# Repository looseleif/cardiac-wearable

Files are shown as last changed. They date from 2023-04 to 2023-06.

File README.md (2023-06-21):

<h1> aWear Monitor: A Passive and Affordable <br>
Atrial Fibrillation Detection Device
</h1>

| _Team member_ 	| _Role_ 	| _Contact_ 	|
|---	|---	|---	|
| Chase Anderson 	| Hardware 	| and08479@umn.edu 	|
| Yuriy Shevchenko 	| Hardware 	| shevc011@umn.edu 	|
| Seth Gunderson 	| Detection algorithm 	| gunde520@umn.edu 	|
| Vaibhav Shirole  	| Firmware 	| shiro019@umn.edu 	|
| Matthew Kukla 	| Firmware 	| kukla013@umn.edu 	|

### What is aWear
Atrial fibrillation is an irregular heartbeat or arrhythmia that can lead to stroke, heart failure, and other heart complications. [7] A severe lack of affordable and easy-to-use, passive, and noninvasive monitoring devices for atrial fibrillation prompted the development of aWear. aWear is a device designed to detect atrial fibrillation in patients passively and wirelessly. The device is designed to be inconspicuous and noninvasive and worn under a regular watch. It monitors the user’s heart activities and if atrial fibrillation is suspected, warns the user. This device uses photoplethysmography to monitor the heart. Detection of atrial fibrillation is done by calculating the coefficient of variation and the turning point ratio after the signal is filtered. The results were a wearable device that lasts approximately 72 hours on a charge and detects atrial fibrillation with an accuracy of 90.48% while remaining under $50 in production cost.
<p align="middle">
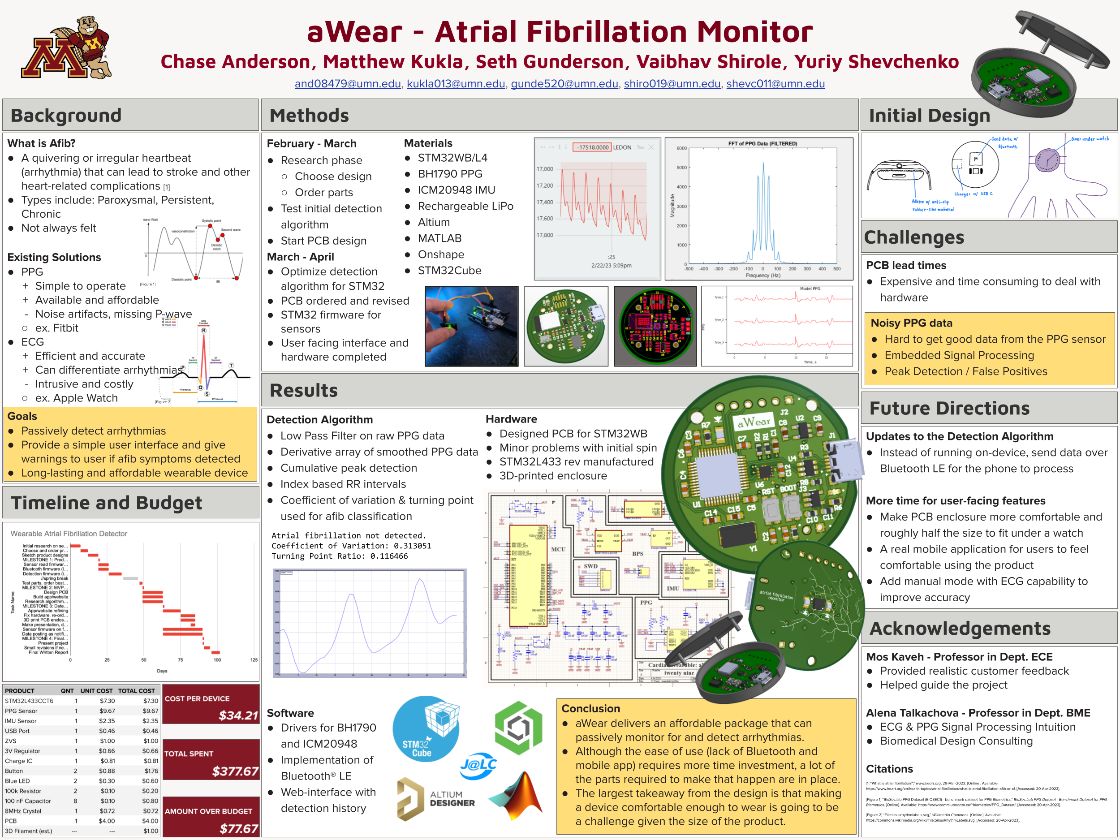
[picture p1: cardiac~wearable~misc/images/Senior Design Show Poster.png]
“design-show-poster”
  
</p>
<p align="middle">
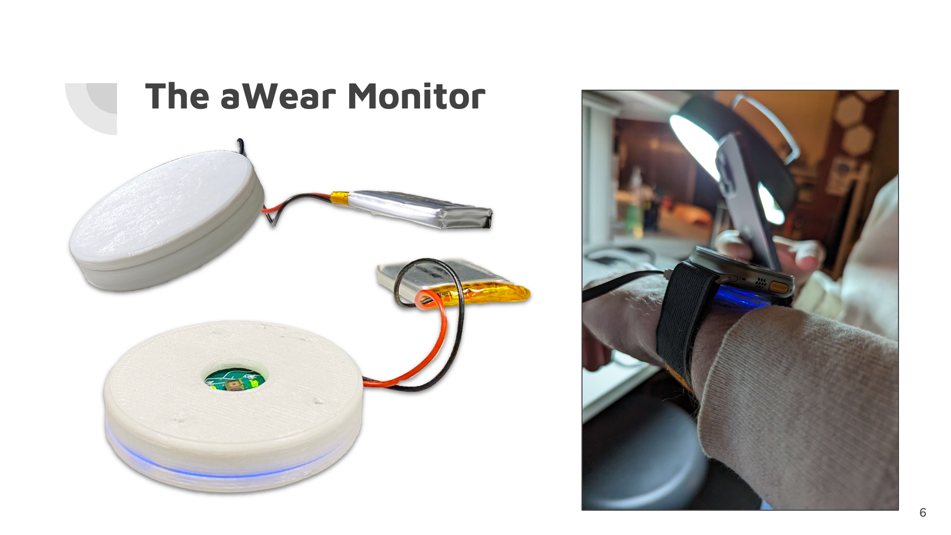
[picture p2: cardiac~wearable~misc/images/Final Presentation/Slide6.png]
“hardware-interface”
  
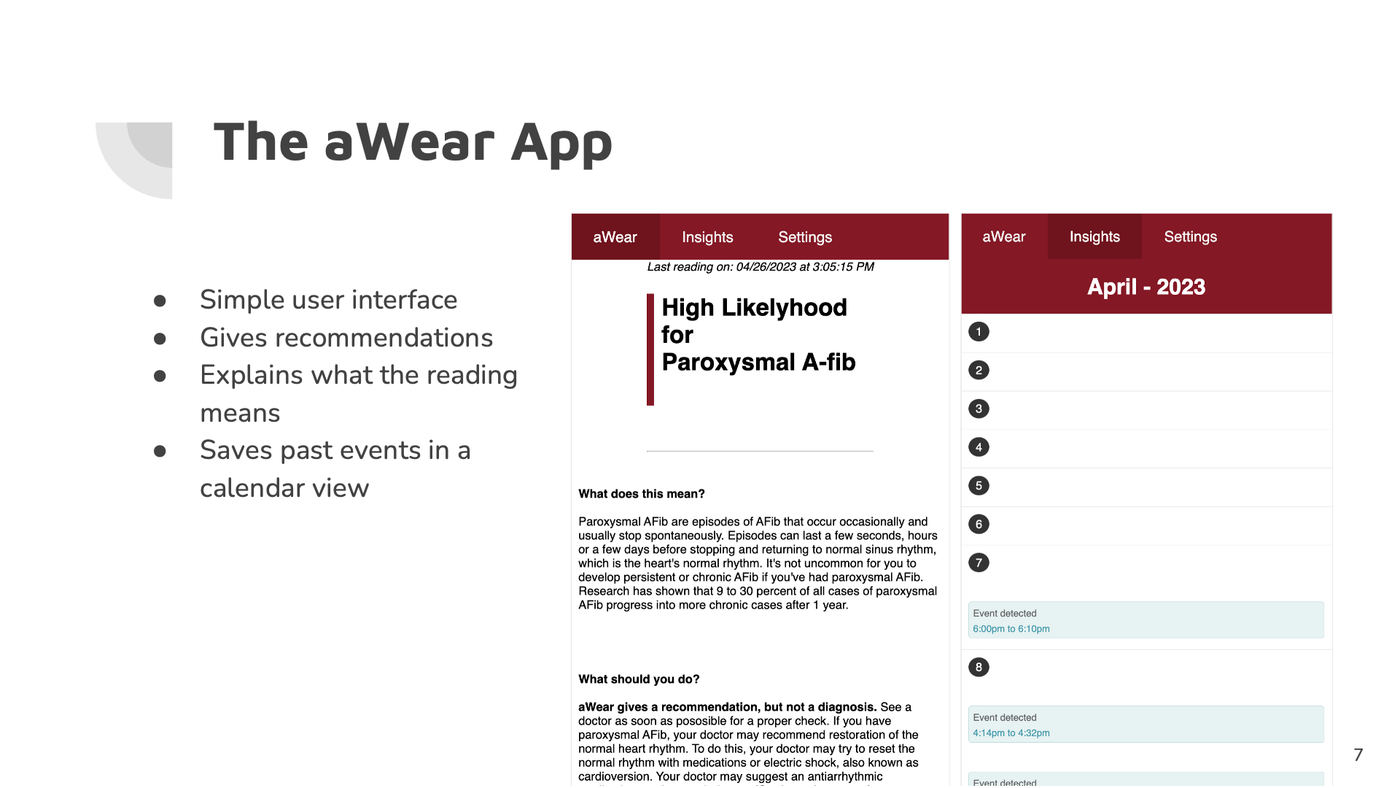
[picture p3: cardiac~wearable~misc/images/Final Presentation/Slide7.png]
“app-interface”
  
</p>

### Compared to the Competition
<p align="middle">
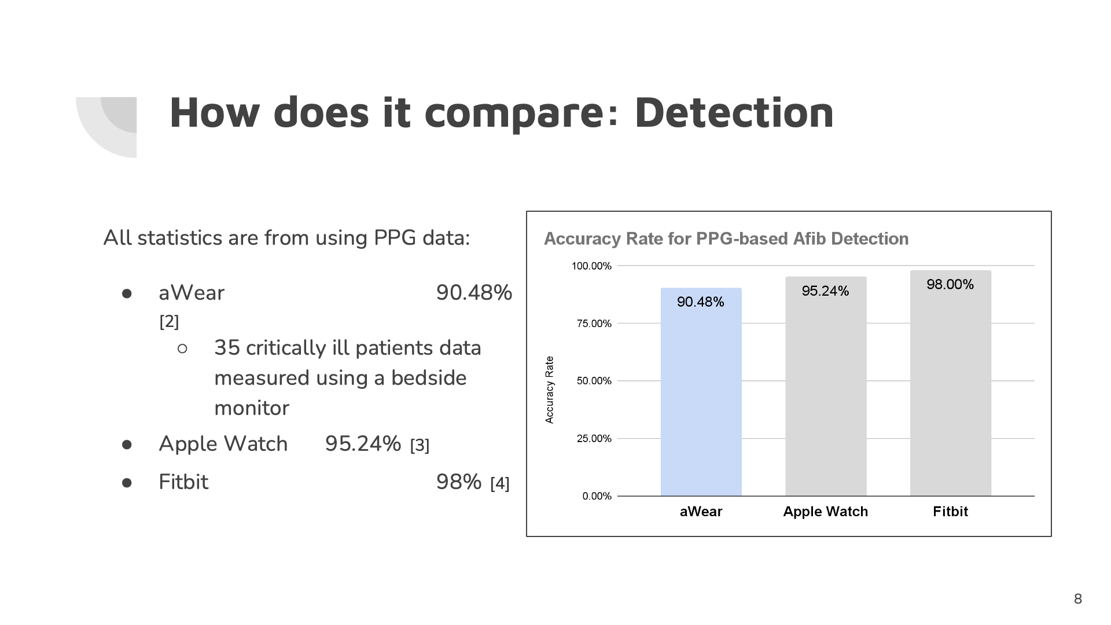
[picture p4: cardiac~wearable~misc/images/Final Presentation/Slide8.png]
“performance”
  
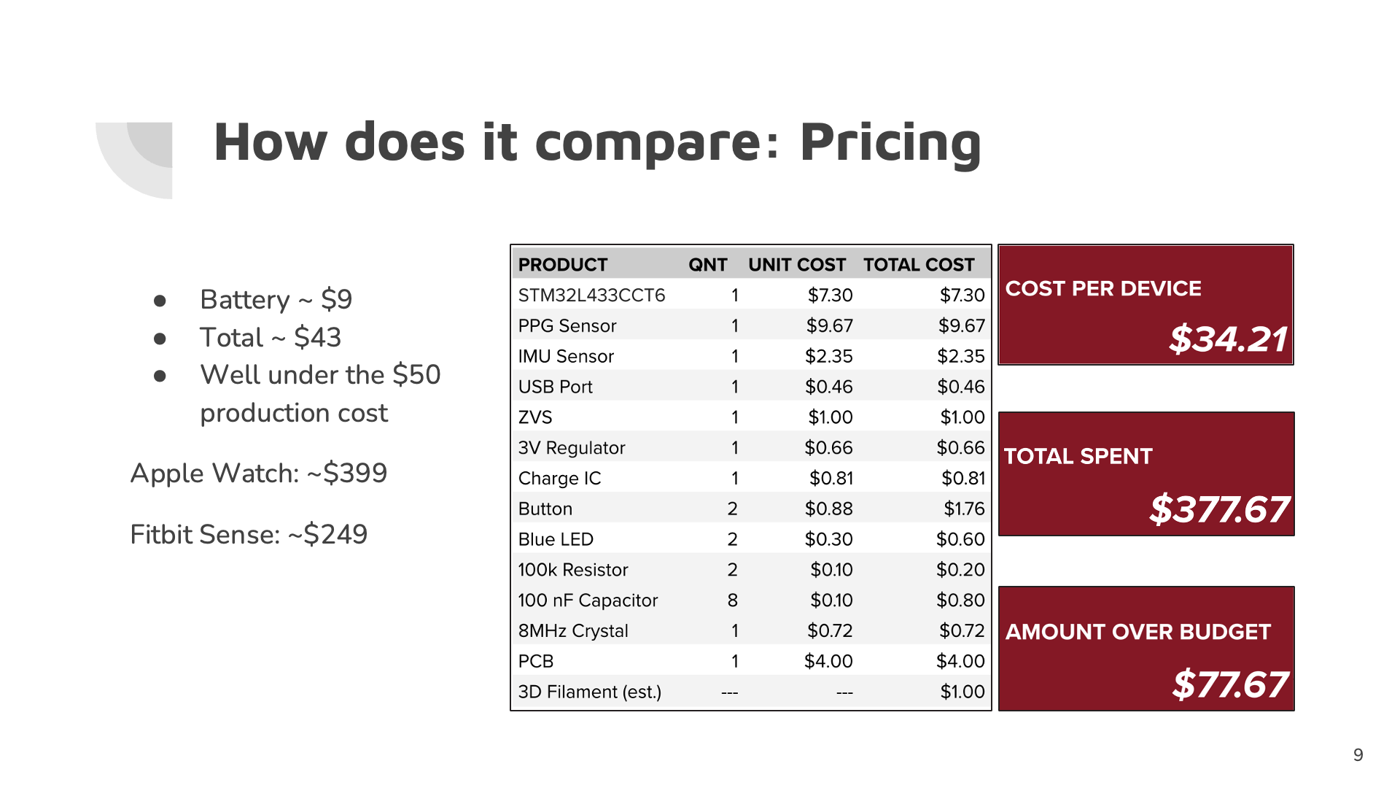
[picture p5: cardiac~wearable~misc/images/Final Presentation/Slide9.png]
“cost-of-production”
  
</p>

## Development

<details>
  <summary>Hardware</summary>
  <p align="middle">
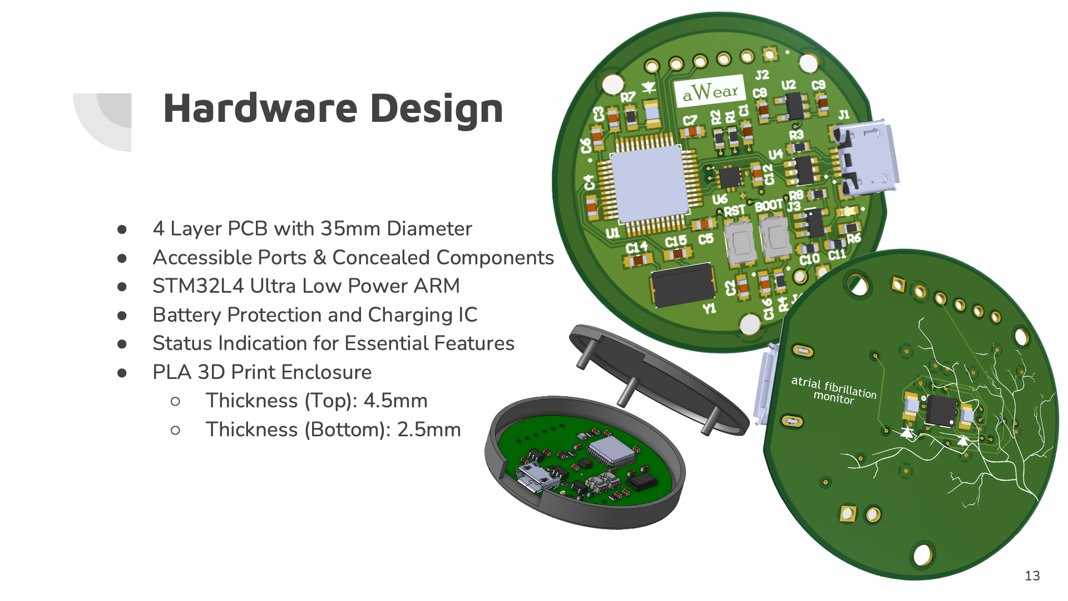
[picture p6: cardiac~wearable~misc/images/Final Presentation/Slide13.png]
“hardware-design”
    
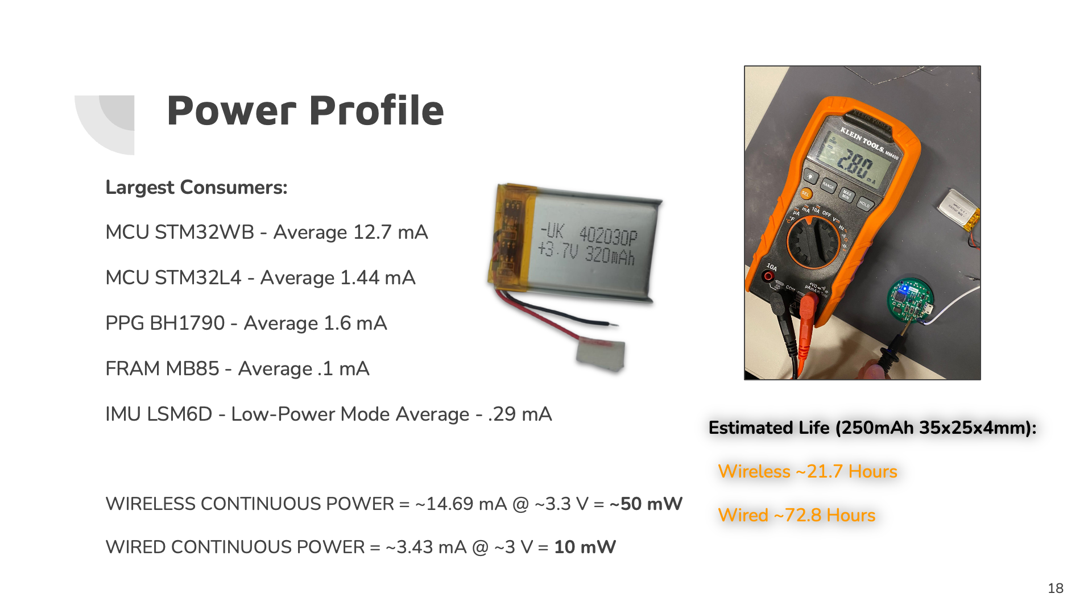
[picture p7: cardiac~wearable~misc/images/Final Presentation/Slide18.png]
“battery-profile”
    
  </p>
</details>

<details>
  <summary>Software</summary>
  <p align="middle">
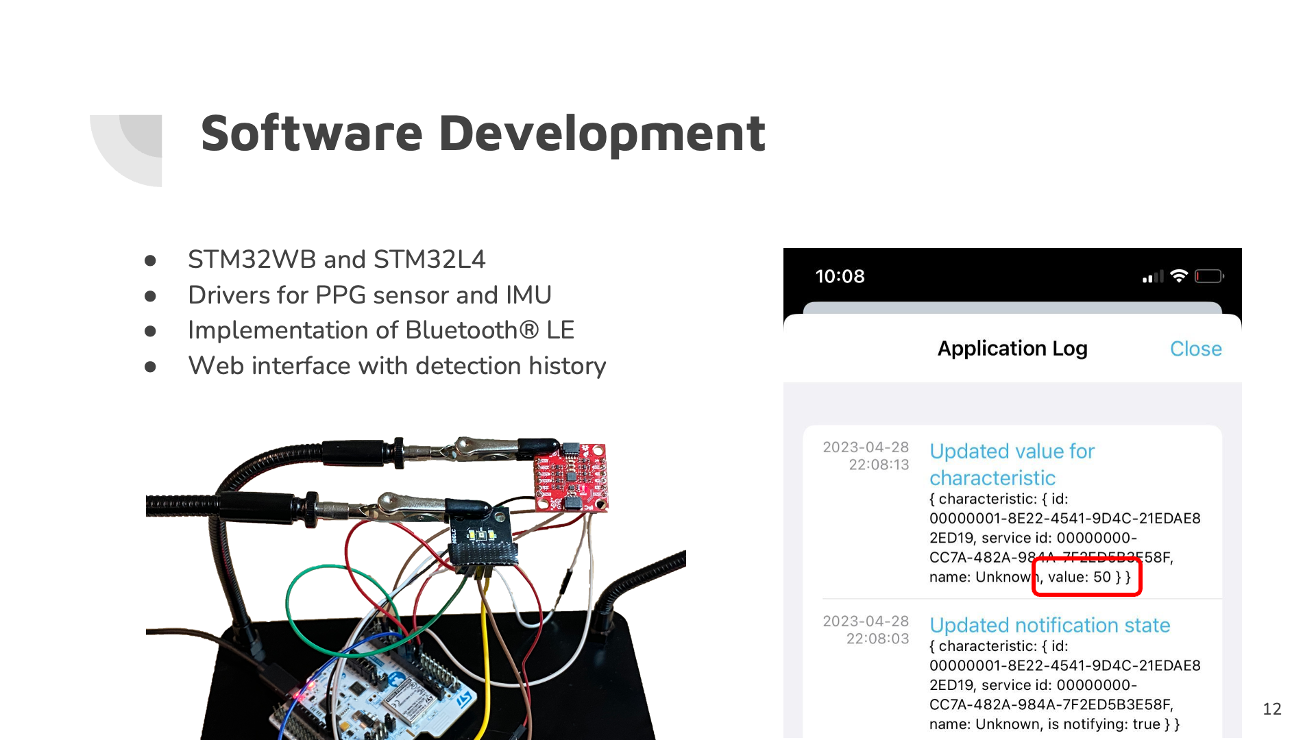
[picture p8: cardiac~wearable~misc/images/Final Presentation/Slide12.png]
    
  </p>
</details>

<details>
  <summary>Detection Algorithm</summary>
  <p align="middle">
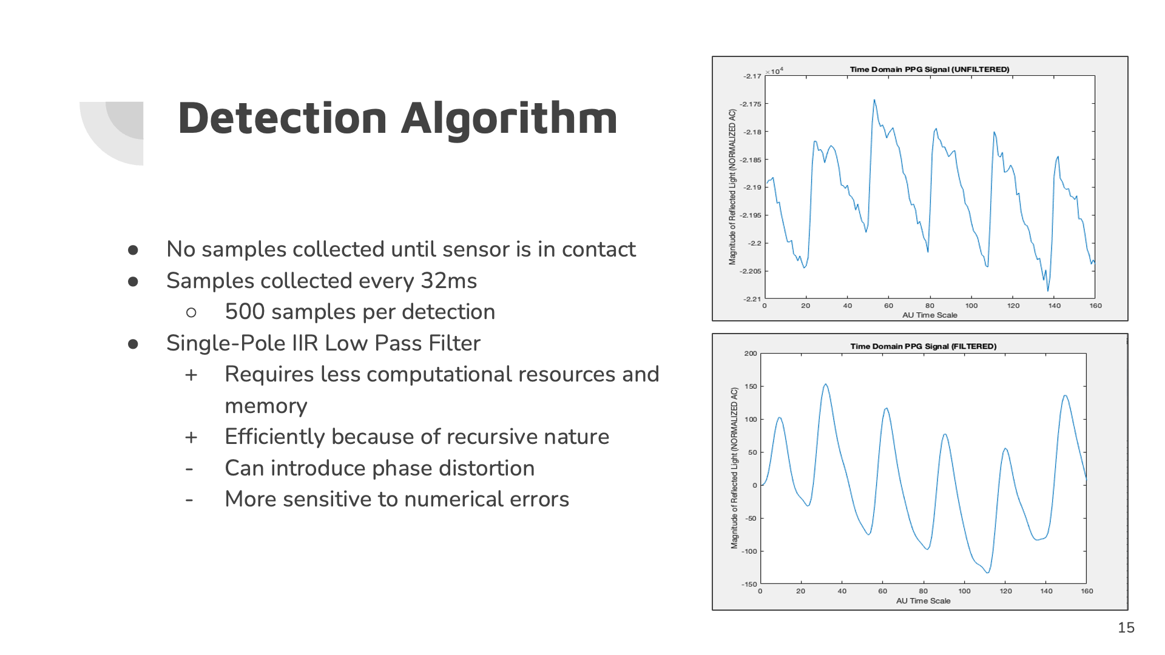
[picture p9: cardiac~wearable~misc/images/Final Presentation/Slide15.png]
“detection-algorithm-1”
    
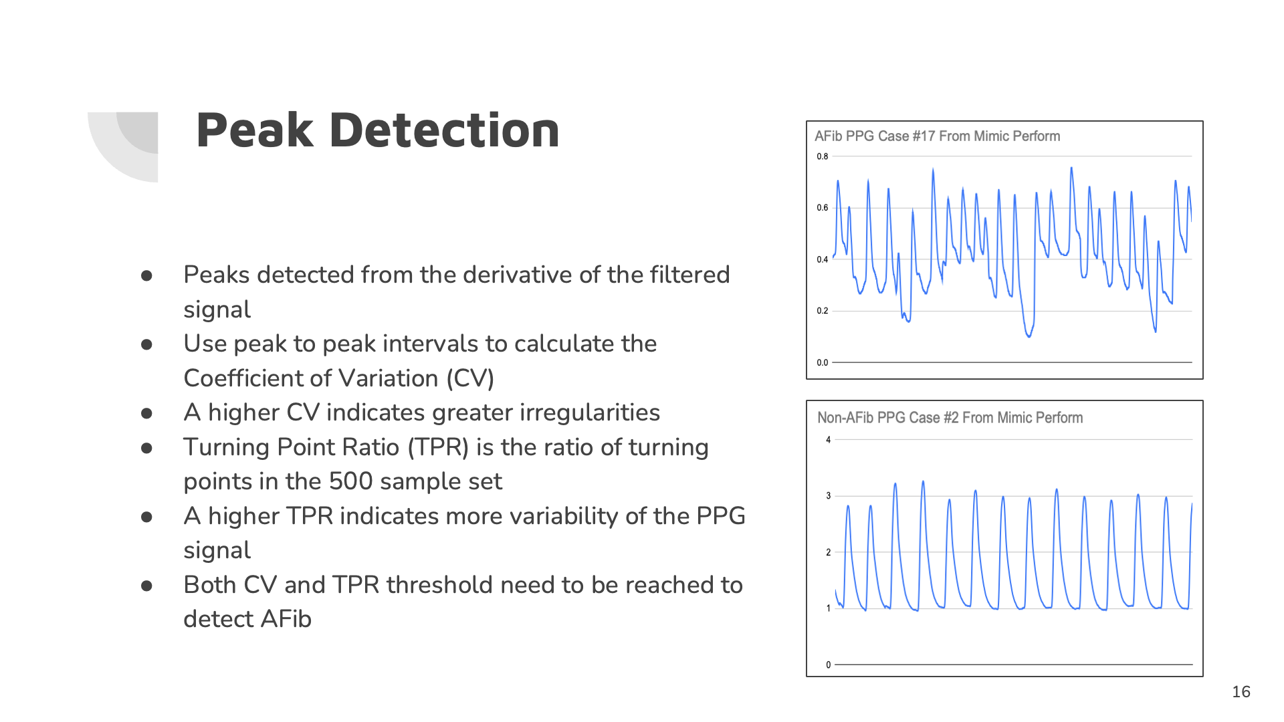
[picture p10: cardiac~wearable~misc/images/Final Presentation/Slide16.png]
“detection-algorithm-2”
    
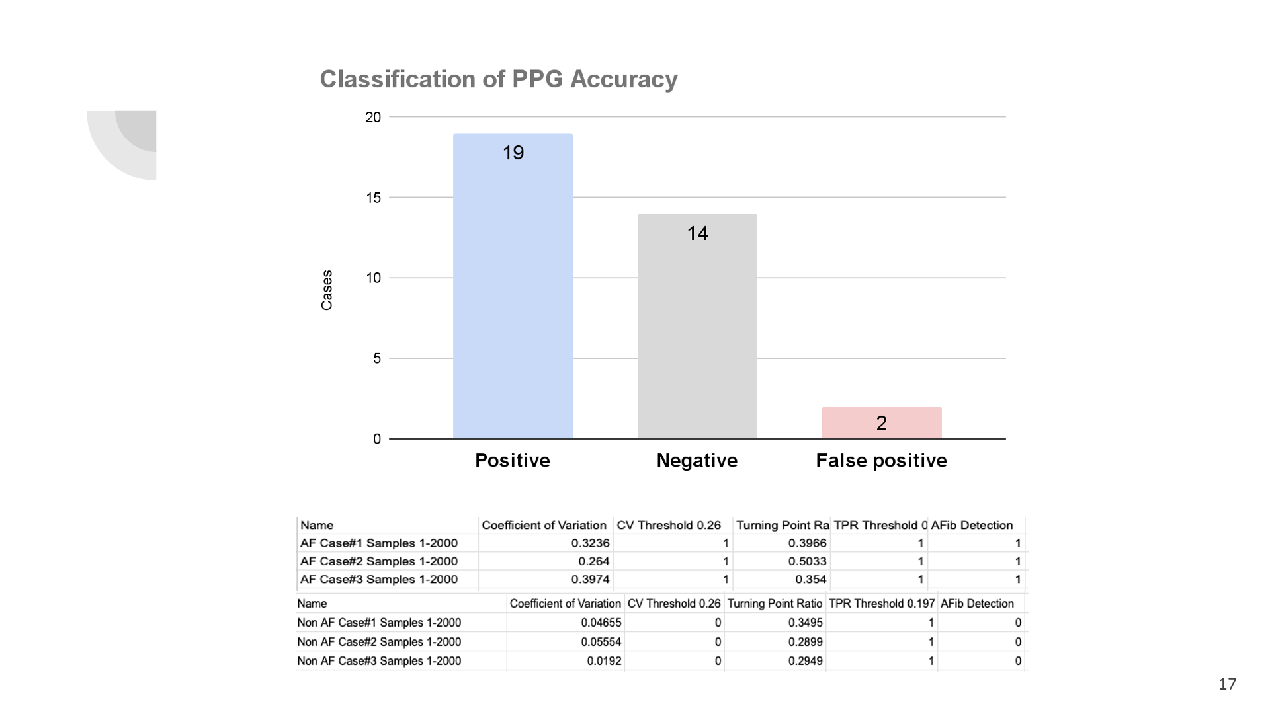
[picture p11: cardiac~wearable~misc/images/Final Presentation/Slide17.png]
“detection-algorithm-3”
    
  </p>
</details>

<details>
  <summary>Project Timeline</summary>
  <p align="middle">
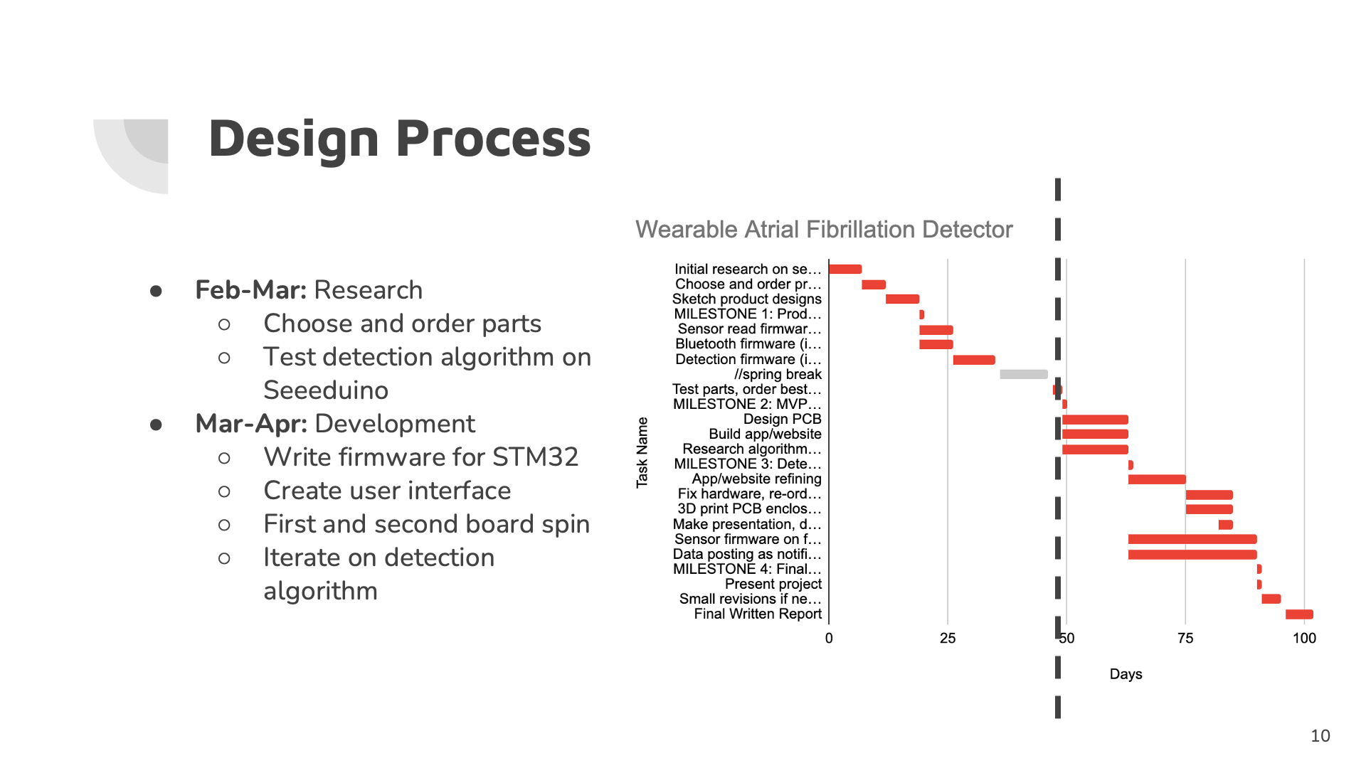
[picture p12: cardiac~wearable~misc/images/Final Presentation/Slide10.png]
    
  </p>
</details>

<br>
<br>
<br>
<br>
<br>
<br>
<br>
<br>
<br>
<br>
<br>
<br>
<br>
<br>
<br>
<br>
<br>
<br>
<br>
<br>

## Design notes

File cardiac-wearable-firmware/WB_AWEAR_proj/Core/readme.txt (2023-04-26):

The USART is configured as follows:
    - BaudRate = 115200 baud
    - Word Length = 8 Bits (7 data bit + 1 parity bit)
    - One Stop Bit
    - Odd parity
    - Hardware flow control disabled (RTS and CTS signals)
    - Reception and transmission are enabled in the time
    
Bluetooth?
custom_app.c line 85

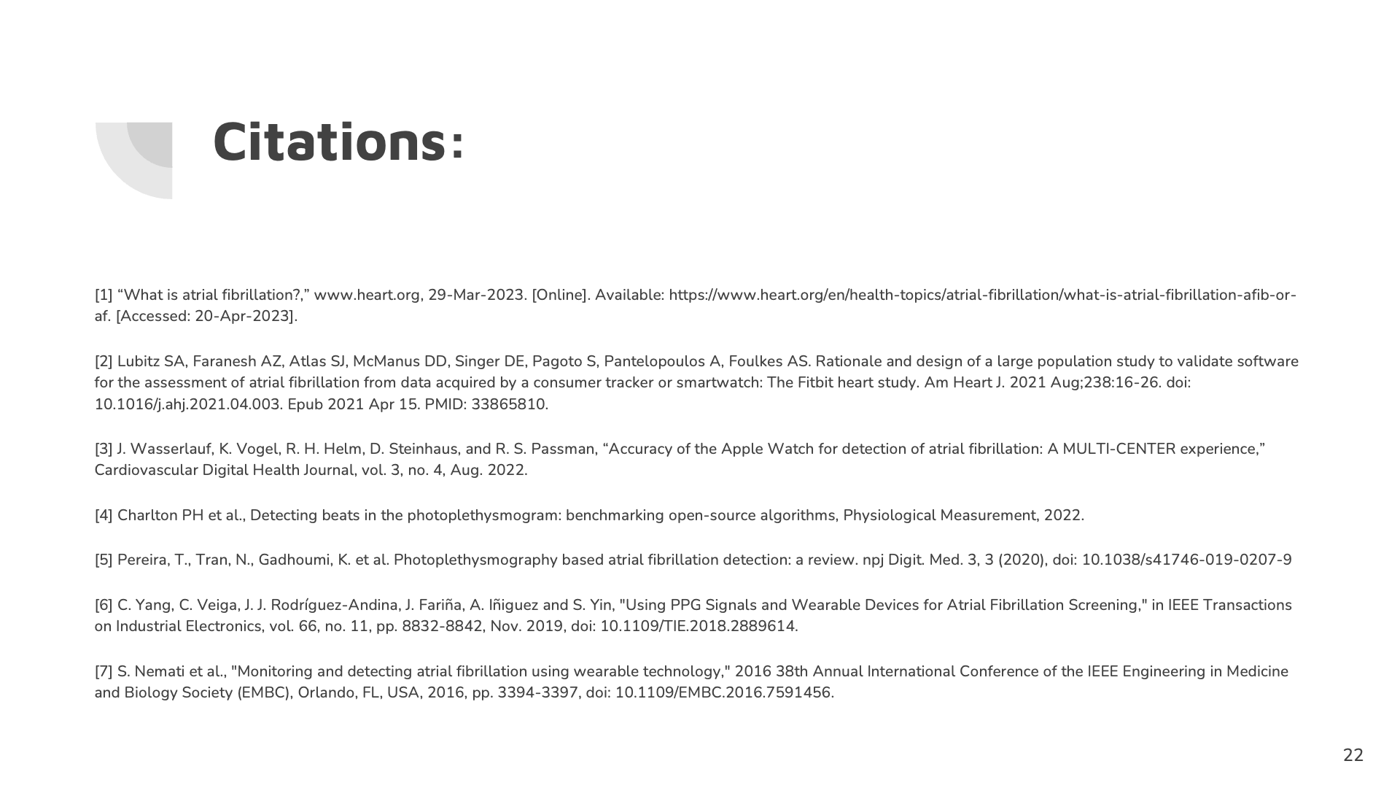
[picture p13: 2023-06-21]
cardiac~wearable~misc/images/Final Presentation/Slide22.png

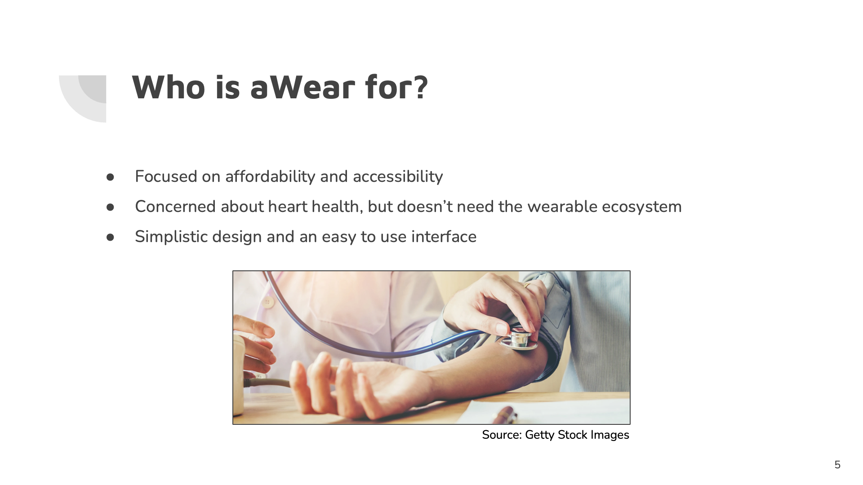
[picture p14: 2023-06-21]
cardiac~wearable~misc/images/Final Presentation/Slide5.png

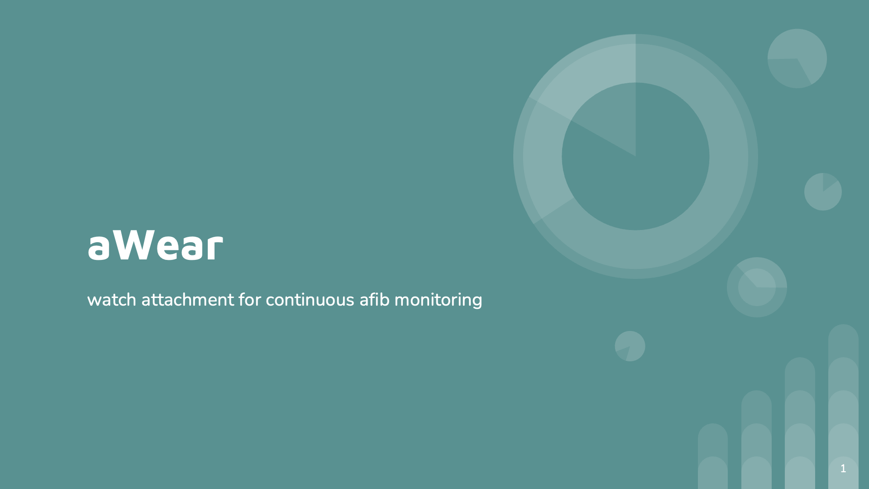
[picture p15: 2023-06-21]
cardiac~wearable~misc/images/Final Presentation/Slide1.png

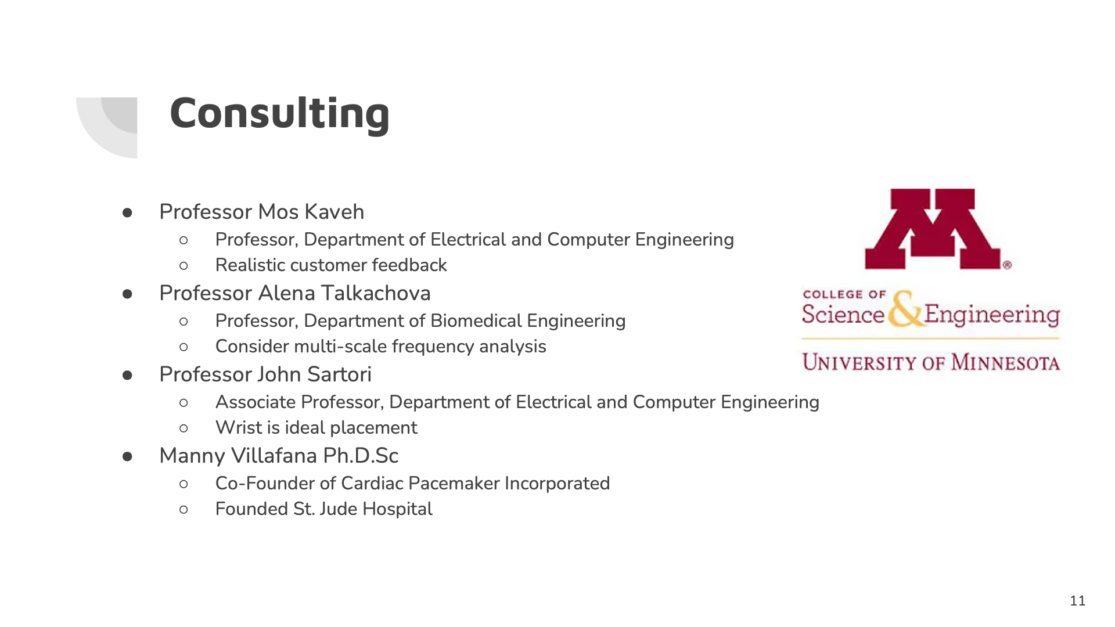
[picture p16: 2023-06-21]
cardiac~wearable~misc/images/Final Presentation/Slide11.png

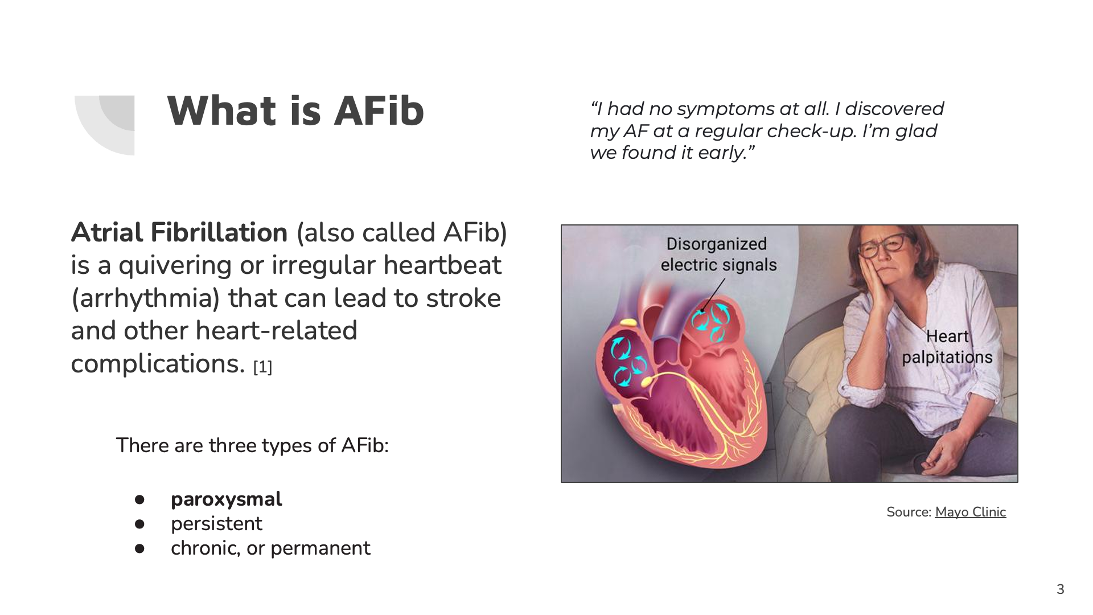
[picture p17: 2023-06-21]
cardiac~wearable~misc/images/Final Presentation/Slide3.png

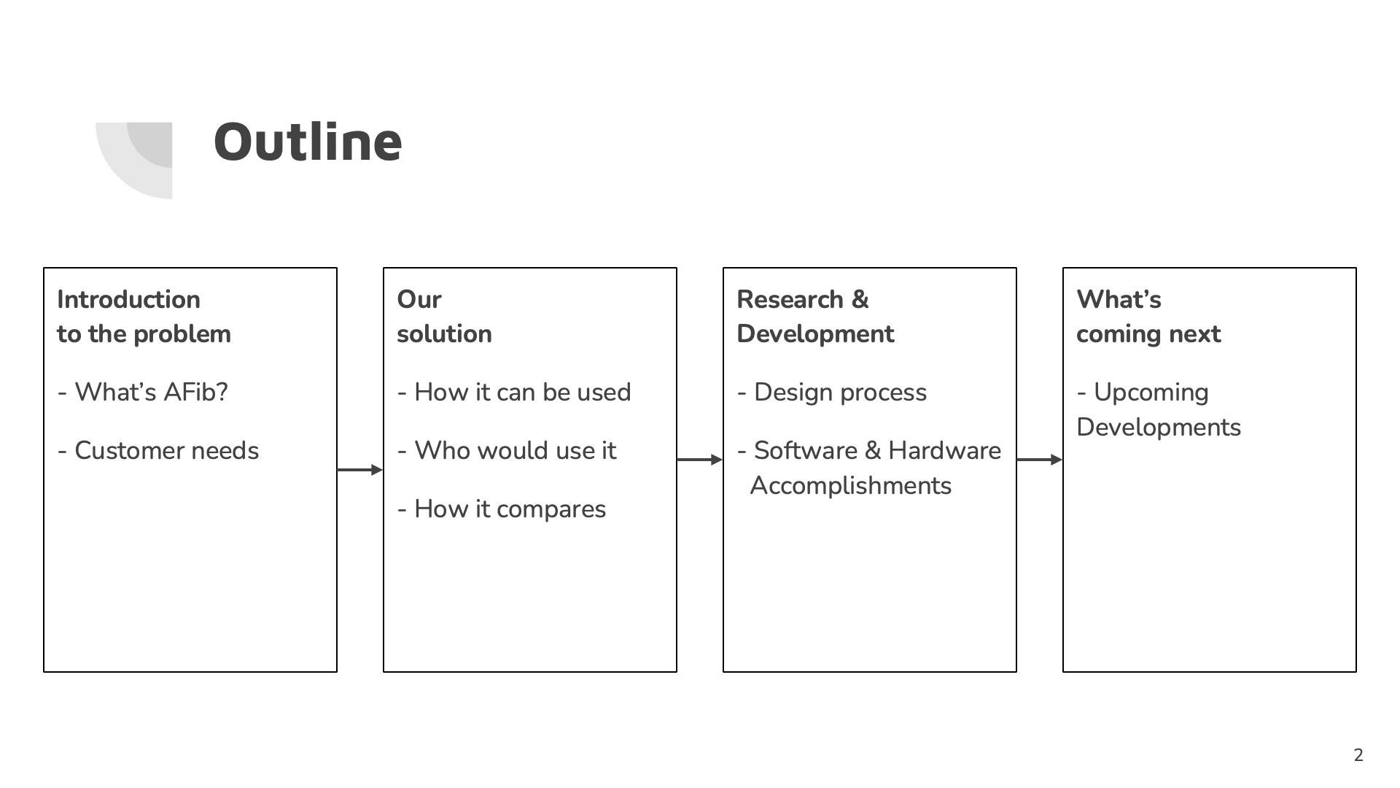
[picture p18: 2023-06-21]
cardiac~wearable~misc/images/Final Presentation/Slide2.png

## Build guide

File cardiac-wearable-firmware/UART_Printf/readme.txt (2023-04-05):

/**
  @page UART_Printf UART Printf example
  
  @verbatim
  ******************** (C) COPYRIGHT 2017 STMicroelectronics *******************
  * @file    UART/UART_Printf/readme.txt 
  * @author  MCD Application Team
  * @brief   Description of the UART Printf example.
  ******************************************************************************
  * @attention
  *
  * Copyright (c) 2017 STMicroelectronics.
  * All rights reserved.
  *
  * This software is licensed under terms that can be found in the LICENSE file
  * in the root directory of this software component.
  * If no LICENSE file comes with this software, it is provided AS-IS.
  *
  ******************************************************************************
   @endverbatim

@par Example Description    

This example shows how to re-route the C library printf function to the UART.
The UART outputs a message on the HyperTerminal.            

The STM32 Nucleo boards integrate the ST-LINK/V2.1 interfacing with the PC and 
offering the following capabilities:
  – Debug and programming port
  – Virtual com port interface
  – Mass storage interface
  – USB power management request for more than 100 mA power

Once connected to your PC via the ST-LINK port, the STM32 Nucleo board is enumerated 
as a serial communication port USART2 and listed under Ports (COM & LPT) of Windows
Device Manager.

This implementation shows how to retarget the C library printf function to the UART
in order to output the printf message on the Hyperterminal using USART2 interface 
connected to ST-LINK MCU in order to support Virtual Com Port.

The communication port USART2 is configured as follows:
    - BaudRate = 9600 baud  
    - Word Length = 8 Bits
    - One Stop Bit
    - ODD parity
    - Hardware flow control disabled (RTS and CTS signals)
    - Receive and transmit enabled

To identify the Nucleo board VCP, you have just to perform the follwing actions on
your Windows PC: 
    - Click Start, and enter Device Manager into the Search field. Click Device Manager .
    - Double-click Ports (COM & LPT).
    - Find the Nucleo board VCP: STMicroelectronics STLink Virtual COM Port (COM..)

To receive the printf output message on the Hyperterminal, apply this configuration
on your serial terminal:       
    - Port name = COM.. (already identified on Device Manager)
    - Word Length = 7 Bits
    - One Stop Bit
    - Odd parity
    - BaudRate = 9600 baud
    - flow control: None 

@note Care must be taken when using HAL_Delay(), this function provides accurate delay (in milliseconds)
      based on variable incremented in SysTick ISR. This implies that if HAL_Delay() is called from
      a peripheral ISR process, then the SysTick interrupt must have higher priority (numerically lower)
      than the peripheral interrupt. Otherwise the caller ISR process will be blocked.
      To change the SysTick interrupt priority you have to use HAL_NVIC_SetPriority() function.
      
@note The application needs to ensure that the SysTick time base is always set to 1 millisecond
      to have correct HAL operation.

@note The clock setting is configured to have the max product performance (max clock frequency) 
      so not optimized in term of power consumption.

@par Keywords

Connectivity, UART, Printf, Baud rate, RS-232, HyperTerminal, full-duplex

@par Directory contents 

  - UART/UART_Printf/Inc/stm32f4xx_hal_conf.h    HAL configuration file
  - UART/UART_Printf/Inc/stm32f4xx_it.h          Interrupt handlers header file
  - UART/UART_Printf/Inc/main.h                  Main program header file  
  - UART/UART_Printf/Src/stm32f4xx_it.c          Interrupt handlers
  - UART/UART_Printf/Src/main.c                  Main program
  - UART/UART_Printf/Src/stm32f4xx_hal_msp.c     HAL MSP module
  - UART/UART_Printf/Src/system_stm32f4xx.c      STM32F4xx system clock configuration file

@par Hardware and Software environment  

  - This example runs on STM32F446xx devices.
    
  - This example has been tested with STMicroelectronics STM32F4xx-Nucleo rev C 
    boards and can be easily tailored to any other supported device 
    and development board.

  - For This example to work properly, a 2.2 µF Capacitor must be present on the board in slot C26.

  - STM32F4xx-Nucleo Set-up    
    - Connect the Nucleo board to your PC with a USB cable type A to mini-B 
      to ST-LINK connector (CN1).
    - Please ensure that the ST-LINK connector CN2 jumpers are fitted.

@par How to use it ? 

In order to make the program work, you must do the following :
 - Open your preferred toolchain 
 - Rebuild all files and load your image into target memory
 - Run the example

 */

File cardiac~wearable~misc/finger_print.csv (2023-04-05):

-21893 | 21893 |  | 547 | 4378 | 10946 | beta = .15 | 3283 | d/dt | -6 | filtered d/dt | 2791
-21887 | 21887 | 547 | 1080 | 7880 | 16416 |  | 6074 |  | 0 |  | 2372
-21887 | 21887 | 1080 | 1600 | 10681 | 19151 |  | 8446 |  | -5 |  | 2015
-21882 | 21882 | 1600 | 2107 | 12921 | 20516 |  | 10461 |  | 22 |  | 1717
-21904 | 21904 | 2107 | 2602 | 14718 | 21210 |  | 12178 |  | 25 |  | 1462
-21929 | 21929 | 2602 | 3086 | 16160 | 21569 |  | 13640 |  | -3 |  | 1243
-21926 | 21926 | 3086 | 3557 | 17313 | 21747 |  | 14883 |  | 22 |  | 1060
-21948 | 21948 | 3557 | 4016 | 18240 | 21847 |  | 15943 |  | 17 |  | 903
-21965 | 21965 | 4016 | 4465 | 18985 | 21906 |  | 16846 |  | 17 |  | 770
-21982 | 21982 | 4465 | 4903 | 19584 | 21944 |  | 17616 |  | 16 |  | 657
-21998 | 21998 | 4903 | 5330 | 20067 | 21971 |  | 18273 |  | 0 |  | 559
-21998 | 21998 | 5330 | 5747 | 20453 | 21984 |  | 18832 |  | -3 |  | 474
-21995 | 21995 | 5747 | 6153 | 20761 | 21989 |  | 19306 |  | 25 |  | 407
-22020 | 22020 | 6153 | 6550 | 21013 | 22004 |  | 19713 |  | 3 |  | 347
-22023 | 22023 | 6550 | 6937 | 21215 | 22013 |  | 20060 |  | 9 |  | 296
-22032 | 22032 | 6937 | 7314 | 21378 | 22022 |  | 20356 |  | -9 |  | 250
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

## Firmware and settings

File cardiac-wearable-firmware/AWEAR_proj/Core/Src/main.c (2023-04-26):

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
/* Includes ------------------------------------------------------------------*/
#include "main.h"

/* USER CODE BEGIN Includes */
#include <BH1790GLC.h>
#include <ICM20948.h>
#include <stdio.h>			//not sure if this is necessary?
#include <math.h>

#define PERIOD (uint32_t)1048			//TO DO: CHECK THE TIMER VAL: I think this is 32 Hz?
#define TIMEOUT (uint32_t)0				//goes to compare register?

#define READY 1
#define BUSY 0

/* USER CODE END Includes */

I2C_HandleTypeDef hi2c1;

LPTIM_HandleTypeDef hlptim1;

SPI_HandleTypeDef hspi2;

UART_HandleTypeDef huart1;

/* USER CODE BEGIN PV */

BH1790GLC 	hrm;			//define the struct for the ppg sensor
ICM20948	imu;			//define the struct for the imu
uint8_t 	sensorReady;	//1=ready, 0=busy

/* USER CODE END PV */

void SystemClock_Config(void);
static void MX_GPIO_Init(void);
static void MX_I2C1_Init(void);
static void MX_USART1_UART_Init(void);
static void MX_LPTIM1_Init(void);
static void MX_SPI2_Init(void);
/* USER CODE BEGIN PFP */
#ifdef __GNUC__
#define PUTCHAR_PROTOTYPE int __io_putchar(int ch)
#else
#define PUTCHAR_PROTOTYPE int fputc(int ch, FILE *f)
#endif
/* USER CODE END PFP */

/**
  * @brief  The application entry point.
  * @retval int
  */
int main(void)
{
  /* MCU Configuration--------------------------------------------------------*/

  /* Reset of all peripherals, Initializes the Flash interface and the Systick. */
  HAL_Init();

  /* Configure the system clock */
  SystemClock_Config();

  /* Initialize all configured peripherals */
  MX_GPIO_Init();
  MX_I2C1_Init();
  MX_USART1_UART_Init();
  MX_LPTIM1_Init();
  MX_SPI2_Init();
  /* USER CODE BEGIN 2 */

  /* Set up heart rate sensor */
  uint8_t status;									//see BH1780GLC.h for err codes

  printf("Configuring PPG sensor...");
  HAL_Delay(10);									//wait as a precaution
  status = BH1790GLC_init(&hrm, &hi2c1);			//configure sensor
  if(status != 0){
	  printf("Error configuring sensor. Status code: %d\n\r", status);
	  sensorReady = 0;
  }else{
	  printf("Sensor configured successfully. Status code: %d\n\r", status);
	  sensorReady = 1;
  }

  /* Set up timer */
  if(HAL_LPTIM_TimeOut_Start_IT(&hlptim1, PERIOD, TIMEOUT) != HAL_OK){  //pointer to the handler, period, timeout val to start the timer
	  Error_Handler();
  }

  /* Set up IMU */
  printf("Configuring IMU...");
  HAL_Delay(10);									//wait as a precaution
  ICM_SelectBank(&imu, USER_BANK_0);				//specify register bank
  HAL_Delay(10);									//wait as a precaution
  ICM_PowerOn(&imu, &hspi2);						//configure sensor
  HAL_Delay(10);									//wait as a precaution

  /* USER CODE END 2 */

  /* Infinite loop */
  /* USER CODE BEGIN WHILE */
  while (1)
  {
    /* USER CODE END WHILE */

    /* USER CODE BEGIN 3 */
	if(sensorReady){
		sensorReady = BUSY;		//flag set back to READY in interrupt every 32 ms

		uint8_t err;

		err = get_val(&hrm);
		if(err != 0){
			printf("Could not read sensor. Error code: %d\n\r", err);
		}else{

			if(add_sample(&hrm)==1){
				ppg_calculate(&hrm);
				for(int i = 100; i < 500; i++){
				//	printf("smooth_array: %d\n", hrm.smooth_array[i]);
				}
			}
		}

	}else{
		//not ready
	}

	// Select User Bank 0
	ICM_SelectBank(&imu, USER_BANK_0);
	ICM_ReadAccelGyroData(&imu);
	HAL_Delay(5);
  }
  /* USER CODE END 3 */
}

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
/* USER CODE BEGIN 4 */

/*
 * Redefinition of the low power timer interrupt
 */
void HAL_LPTIM_CompareMatchCallback(LPTIM_HandleTypeDef *hlptim){
	sensorReady = READY;
	//printf("inside interrupt: sensorReady");
}

/* USER CODE BEGIN 4 */
/**
  * @brief  Retargets the C library printf function to the USART.
  * @param  None
  * @retval None
  */
PUTCHAR_PROTOTYPE
{
  /* Place your implementation of fputc here */
  /* e.g. write a character to the USART1 and Loop until the end of transmission */
  HAL_UART_Transmit(&huart1, (uint8_t *)&ch, 1, HAL_MAX_DELAY);

  return ch;
}

/* USER CODE END 4 */
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


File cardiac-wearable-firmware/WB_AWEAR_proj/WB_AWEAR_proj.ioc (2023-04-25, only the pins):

Mcu.UserName=STM32WB55RGVx
PA1.Signal=SPI1_SCK
PA11.Signal=USB_DM
PA12.Signal=USB_DP
PA13.GPIO_Label=JTMS
PA13.Signal=SYS_JTMS-SWDIO
PA14.GPIO_Label=JTCK
PA14.Signal=SYS_JTCK-SWCLK
PA6.Signal=SPI1_MISO
PA7.Signal=SPI1_MOSI
PB0.GPIO_Label=LD2 [Green Led]
PB0.Signal=GPIO_Output
PB1.GPIO_Label=LD3 [Red Led]
PB1.Signal=GPIO_Output
PB3.Signal=GPIO_Output
PB4.Signal=GPIO_Output
PB5.GPIO_Label=LD1 [Blue Led]
PB5.Signal=GPIO_Output
PB6.GPIO_Label=STLINK_RX
PB6.Signal=USART1_TX
PB7.GPIO_Label=STLINK_TX
PB7.Signal=USART1_RX
PB8.Signal=I2C1_SCL
PB9.Signal=I2C1_SDA
PC13.Signal=SYS_WKUP2
PC14-OSC32_IN.Signal=RCC_OSC32_IN
PC15-OSC32_OUT.Signal=RCC_OSC32_OUT
PC4.GPIO_Label=B1 [Push Button]
PC4.Signal=GPIO_Input
PD0.GPIO_Label=B2 [Push Button]
PD0.Signal=GPIO_Input
PD1.GPIO_Label=B3 [Push Button]
PD1.Signal=GPIO_Input

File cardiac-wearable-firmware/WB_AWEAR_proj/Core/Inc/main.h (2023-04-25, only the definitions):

#define B1_Pin GPIO_PIN_4
#define B1_GPIO_Port GPIOC
#define LD2_Pin GPIO_PIN_0
#define LD2_GPIO_Port GPIOB
#define LD3_Pin GPIO_PIN_1
#define LD3_GPIO_Port GPIOB
#define JTMS_Pin GPIO_PIN_13
#define JTMS_GPIO_Port GPIOA
#define JTCK_Pin GPIO_PIN_14
#define JTCK_GPIO_Port GPIOA
#define B2_Pin GPIO_PIN_0
#define B2_GPIO_Port GPIOD
#define B3_Pin GPIO_PIN_1
#define B3_GPIO_Port GPIOD
#define LD1_Pin GPIO_PIN_5
#define LD1_GPIO_Port GPIOB
#define STLINK_RX_Pin GPIO_PIN_6
#define STLINK_RX_GPIO_Port GPIOB
#define STLINK_TX_Pin GPIO_PIN_7
#define STLINK_TX_GPIO_Port GPIOB
#define ICM_CS_Pin GPIO_PIN_4	//previously PB3, set GPIO_Output on PB4 for now
#define ICM_CS_GPIO_Port GPIOB
#define ICM_SCK_Pin GPIO_PIN_1
#define ICM_SCK_GPIO_Port GPIOA
#define ICM_MISO_Pin GPIO_PIN_6
#define ICM_MISO_GPIO_Port GPIOA
#define ICM_MOSI_Pin GPIO_PIN_7
#define ICM_MOSI_GPIO_Port GPIOA

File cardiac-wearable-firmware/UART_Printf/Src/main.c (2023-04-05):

/**
  ******************************************************************************
  * @file    UART/UART_Printf/Src/main.c 
  * @author  MCD Application Team
  * @brief   This example shows how to retarget the C library printf function 
  *          to the UART.
  ******************************************************************************
  * @attention
  *
  * Copyright (c) 2017 STMicroelectronics.
  * All rights reserved.
  *
  * This software is licensed under terms that can be found in the LICENSE file
  * in the root directory of this software component.
  * If no LICENSE file comes with this software, it is provided AS-IS.
  *
  ******************************************************************************
  */

/* Includes ------------------------------------------------------------------*/
#include "main.h"
#include <math.h>
/** @addtogroup STM32F4xx_HAL_Examples
  * @{
  */

/** @addtogroup UART_Printf
  * @{
  */ 

/* Private typedef -----------------------------------------------------------*/
/* Private define ------------------------------------------------------------*/
/* Private macro -------------------------------------------------------------*/
/* Private variables ---------------------------------------------------------*/
/* UART handler declaration */
UART_HandleTypeDef UartHandle;

/* Private function prototypes -----------------------------------------------*/
#ifdef __GNUC__
  /* With GCC, small printf (option LD Linker->Libraries->Small printf
     set to 'Yes') calls __io_putchar() */
  #define PUTCHAR_PROTOTYPE int __io_putchar(int ch)
#else
  #define PUTCHAR_PROTOTYPE int fputc(int ch, FILE *f)
#endif /* __GNUC__ */
static void SystemClock_Config(void);
static void Error_Handler(void);

/* Private functions ---------------------------------------------------------*/

/**
  * @brief  Main program
  * @param  None
  * @retval None
  */
int main(void)
{
  /* STM32F4xx HAL library initialization:
       - Configure the Flash prefetch, instruction and Data caches
       - Configure the Systick to generate an interrupt each 1 msec
       - Set NVIC Group Priority to 4
       - Global MSP (MCU Support Package) initialization
     */
  HAL_Init();
  
  /* Configure the system clock to 180 MHz */
  SystemClock_Config();
   
  /*##-1- Configure the UART peripheral ######################################*/
  /* Put the USART peripheral in the Asynchronous mode (UART Mode) */
  /* UART1 configured as follows:
      - Word Length = 8 Bits
      - Stop Bit = One Stop bit
      - Parity = ODD parity
      - BaudRate = 9600 baud
      - Hardware flow control disabled (RTS and CTS signals) */
  UartHandle.Instance          = USARTx;
  
  UartHandle.Init.BaudRate     = 9600;
  UartHandle.Init.WordLength   = UART_WORDLENGTH_8B;
  UartHandle.Init.StopBits     = UART_STOPBITS_1;
  UartHandle.Init.Parity       = UART_PARITY_ODD;
  UartHandle.Init.HwFlowCtl    = UART_HWCONTROL_NONE;
  UartHandle.Init.Mode         = UART_MODE_TX_RX;
  UartHandle.Init.OverSampling = UART_OVERSAMPLING_16;
    
  if(HAL_UART_Init(&UartHandle) != HAL_OK)
  {
    /* Initialization Error */
    Error_Handler(); 
  }
  
  /* Output a message on Hyperterminal using printf function */
  printf("\n\r UART Printf Example: retarget the C library printf function to the UART\n\r");


  uint16_t raw_data[160] = {

		  21893,
		  21887,
		  21887,
		  21882,
		  21904,
		  21929,
		  21926,
		  21948,
		  21965,
		  21982,
		  21998,
		  21998,
		  21995,
		  22020,
		  22023,
		  22032,
		  22023,
		  22035,
		  22045,
		  22041,
		  22026,
		  21952,
		  21857,
		  21817,
		  21818,
		  21834,
		  21832,
		  21838,
		  21856,
		  21842,
		  21831,
		  21825,
		  21828,
		  21834,
		  21848,
		  21867,
		  21896,
		  21897,
		  21902,
		  21896,
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
  };

  uint16_t smooth_array[160];
  int deriv_array[159];

  uint16_t raw_data_1;
  float smooth_data_1 = 0;
  float lpf_beta = 0.15;

  for(int i = 0; i < 160; i++){

	  raw_data_1 = raw_data[i];
	  smooth_data_1 = smooth_data_1 - (lpf_beta*(smooth_data_1 - raw_data_1));
	  smooth_array[i] = smooth_data_1;
	  if(i!=0){


		  int deriv = (int)smooth_array[i] - (int)smooth_array[i-1];
		  if(deriv<255 || deriv>-255){

			 deriv_array[i] = deriv;

		  } else {

			 deriv_array[i] = deriv_array[i-1];

		  }

	  }

  }

  int pos = 0;
  int neg = 0;

  int pos_check = 0;
  int neg_check = 0;

  int peak_vals[20] = {};
  int peak_count = 0;


  for(int j = 0; j < 159; j++){



	  if(deriv_array[j]>0 && pos_check==0){

		  neg = 0;
		  pos++;

		  if(pos==3){

			  pos_check = 1;

		  }

	  } else if (deriv_array[j]<0 && pos_check==1) {

		  pos = 0;
		  neg++;

		  if(neg==3){

			  neg_check = 1;
			  peak_vals[peak_count] = j;
			  peak_count++;

			  pos_check = 0;
			  neg_check = 0;

		  }


	  } else if (deriv_array[j]<0 && pos_check==0){
		  pos = 0;
	  }

  }

  for(int k = 0; k<20; k++){

	  printf("PEAK DETECTED: %d\n", peak_vals[k]);

  }





  while (1)
  {

      // Function that brings Fresh Data into RawData


  }
}

/**
  * @brief  Retargets the C library printf function to the USART.
  * @param  None
  * @retval None
  */
PUTCHAR_PROTOTYPE
{
  /* Place your implementation of fputc here */
  /* e.g. write a character to the EVAL_COM1 and Loop until the end of transmission */
  HAL_UART_Transmit(&UartHandle, (uint8_t *)&ch, 1, 0xFFFF); 

  return ch;
}
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

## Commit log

2023-02-21 testing bh sensor
2023-02-21 initial sensor readings
2023-02-23 hardware and some firmware for fun
    [cardiac_wearable_hardware.PrjPcb, wearable.PcbDoc, wearable.SchDoc]
2023-02-23 working sensor readings from nrf52840
2023-02-23 addded BLE connection and working with commented out sensor reading
2023-02-23 inital sym+foot planning for SCH/PCB
    [cardiac_wearable_hardware.PrjPcb, wearable.PcbDoc, wearable.SchDoc]
2023-02-23 thoughts for STM32WB, in prog altium design
    [cardiac_wearable_hardware.PrjPcb, wearable.PcbDoc, wearable.SchDoc]
2023-02-24 some more files
    [wearable.SchDoc]
2023-02-24 added csv and finish pcb/sch
    [wearable.PcbDoc, wearable.SchDoc]
2023-02-24 done again
    [finger_print.csv]
2023-02-24 more hardware additions
    [wearable.PcbDoc, wearable.SchDoc]
2023-03-15 working on more hardware
    [wearable.PcbDoc, wearable.SchDoc]
2023-03-20 more hardware!
    [cardiac_wearable_hardware.PrjPcb, wearable.PcbDoc, wearable.SchDoc]
2023-03-21 added STM32 BLE heart rate project
2023-03-22 even more hardware
    [wearable.PcbDoc, wearable.SchDoc]
2023-03-22 forgot pcbprj
2023-03-23 finalized schDoc
    [wearable.PcbDoc, wearable.SchDoc]
2023-03-23 in prog routing
    [wearable.PcbDoc, wearable.SchDoc]
2023-03-23 98% there
    [wearable.PcbDoc, wearable.SchDoc]
2023-03-23 ready for design review
    [cardiac_wearable_hardware.PrjPcb, wearable.PcbDoc, wearable.SchDoc]
2023-03-25 archive of esp32 testing with sensors
2023-03-26 test proj for ppg sensor communication
2023-03-27 low level drivers for bh1790
    Untested, but they're very simple so I hope they work.
    Will need to declare a BH1790GLC object in main to use it.
2023-03-28 wrote test for initial hr sensor communication
2023-03-28 fixed read and write input reg length
    [BH1790GLC.c, main.c]
2023-03-28 stash of changes to try with different sensor
2023-03-29 working i2c and updated mem read checks
2023-03-29 print sensor data to serial
2023-03-29 added a reset and refresh method
    also a little bit of cleanup
    [BH1790GLC.c, BH1790GLC.h]
2023-03-29 initial config for low power timer
2023-03-29 32 Hz internal interrupt for reading the sensor
    need to double check that 32 Hz speed, but it looks right visually
2023-03-29 flag to read sensor every 32 ms
2023-04-05 forgot excel
    [finger_print.csv]
2023-04-09 Revert "got BLE working"
    This reverts commit 1ba27d6191e55f1914a7bc1f14e2225eee97b962.
    [WB_AWEAR_proj.ioc, app_conf.h]
2023-04-09 auto generated print
2023-04-09 spi settings configured
2023-04-10 untested icm20948 drivers
2023-04-10 adjusted driver authors
2023-04-12 real time ppg
    working
    [wearable.PcbDoc]
2023-04-13 initial working accelerometer drivers
    i dont know what the raw data values mean though
2023-04-13 added 33TT6
    [wearable.SchDoc, wearableSTEP.step]
2023-04-13 restructured driver files to be more readable
2023-04-13 started error handling a little
    [ICM20948.c, main.c]
2023-04-13 fixedaccelerometer readings to be signed
    [ICM20948.c, main.c]
2023-04-14 hardware baby
    [cardiac_wearable_hardware.PrjPcb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]
2023-04-18 speed up init by disabling magnetometer writes
2023-04-18 Coefficients of Variation and Turning Point Ratio
    [wearableSTEP.step]
2023-04-19 Reject false positives with ppg[0]
    [wearable.PcbDoc]
2023-04-20 Current Algorithm
2023-04-23 added printf and timer
    don't know if any of this works!
2023-04-23 accelerometer code
    The threshold should be changed based on how sensitive we want to not collect data.
2023-04-24 updated main.c to read ppg, added drivers+updated main.h
2023-04-24 enable floats in printf
2023-04-24 fixed main so it doesnt get wiped
    [main.c]
2023-04-25 Current Code
2023-06-21 added spacers to readme

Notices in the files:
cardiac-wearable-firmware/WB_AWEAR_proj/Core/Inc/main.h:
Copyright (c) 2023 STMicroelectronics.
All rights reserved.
